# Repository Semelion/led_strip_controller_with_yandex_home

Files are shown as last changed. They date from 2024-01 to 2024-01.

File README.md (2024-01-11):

# led_strip_controller_with_yandex_home
Контролер с возможностью подключения к умному дому Яндекс

Идея проекта сделать основу для проектов умного дома с интеграцией в умный дом Яндекс. Изначально возникла потребность управлять светодиодной лентой с возможностью димирования, но представленные контроллеры не внушали доверия

### Компоненты
- esp8266 для управления
- оптопары для управления транзисторами и другой нагрузкой 5 вольт
- транзистор IRF44N для управления светодиодной ленты
- кнопка без фиксации с подсветкой
- блок питания 12 вольт (расчитанный по мощности под ленту)
- понижающий dc-dc преобразователь для питания платы и компонентов

## Печатная плата
Печатная плата спроектирована в KiCad, исходники можно посмотреть в `kitchen_light_pcb/`, а библиотеки компенонтов использованные лежат в `kicad_lib`

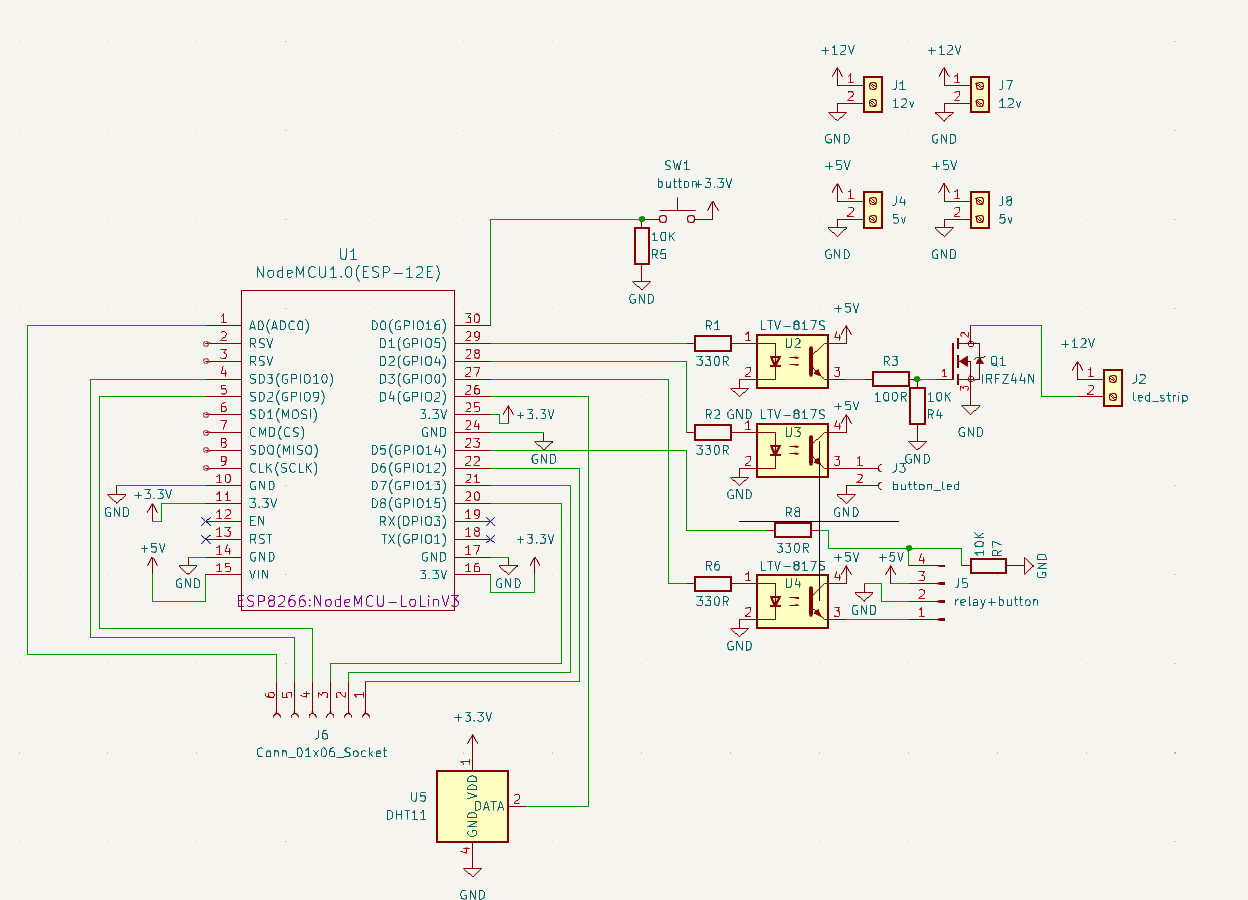
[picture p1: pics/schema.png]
Схема печатной платы

Схема печатной платы

- Разъем J2 для подключения светодиодной ленты
- J1, J7 разьемы 12 вольт на вход
- J4, J8 разьемы 5 вольт на вход
- J6 разьем подключенный к ESP, для подключения чего либо если понадобится
- есть датчик температуры и влажности DHT22
- J5 задумывается для использования реле и кнопки, чтобы встроить в выключатель без нуля
- SW1 контакты для кнопки, в моем случае это внешняя кнопка, крепится в низ шкафа над плитой
- J3 контакты для подсветки кнопки

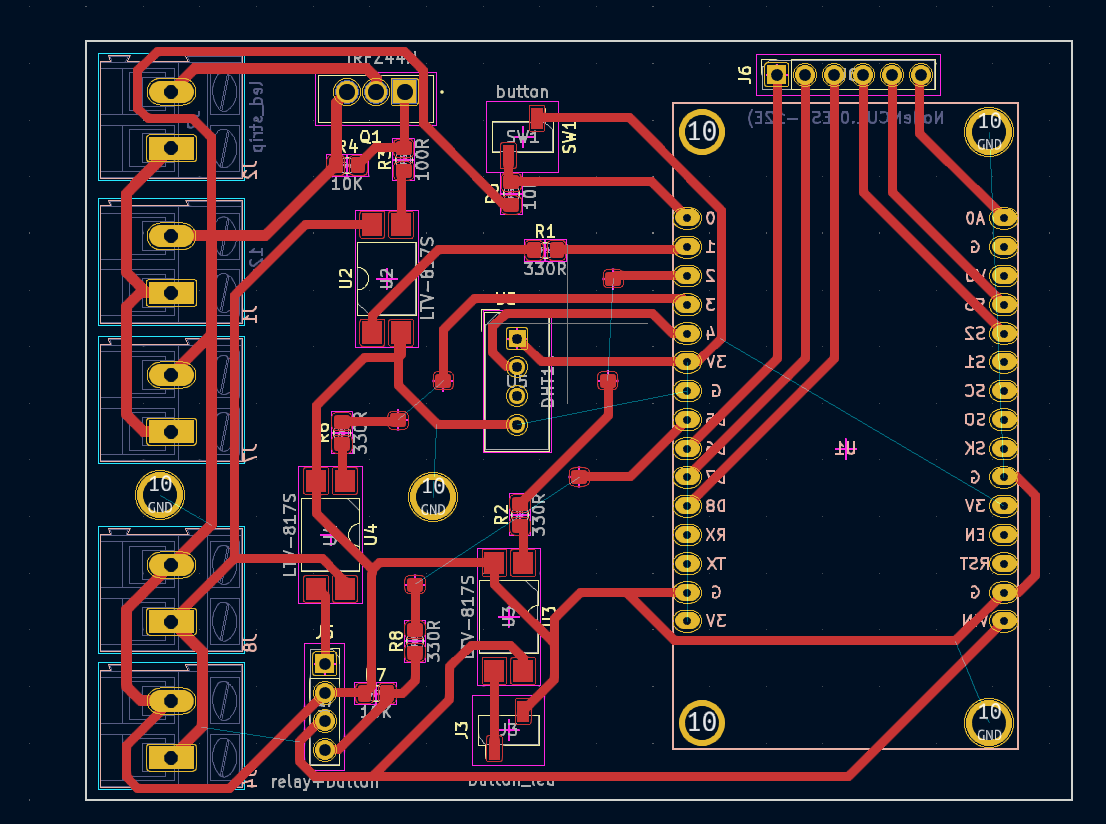
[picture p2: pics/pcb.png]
Разведение печатной платы

Разведение печатной платы

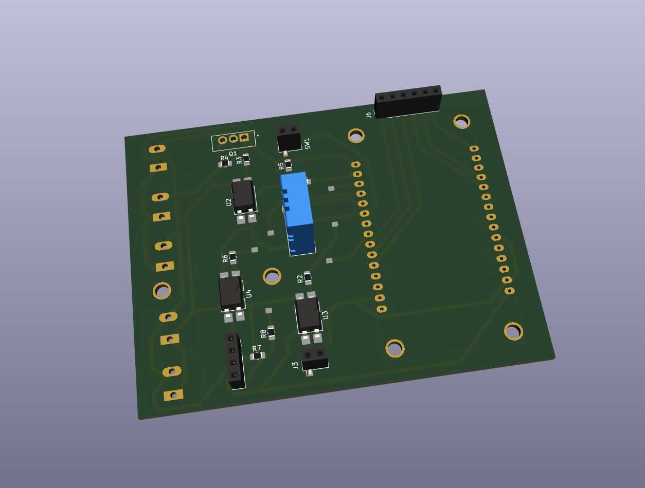
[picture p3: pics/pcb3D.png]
Печатная плата в 3D

Печатная плата в 3D

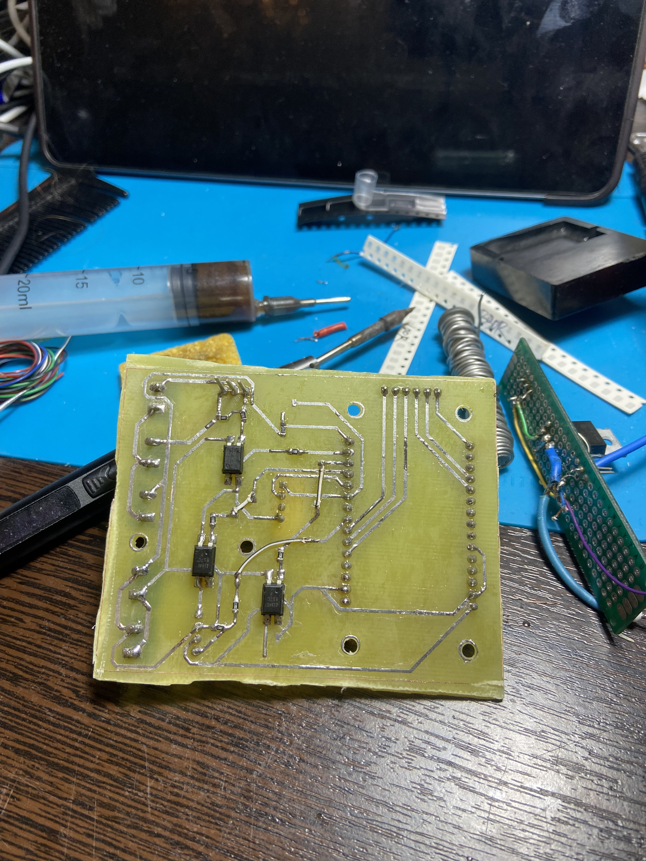
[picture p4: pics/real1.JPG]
Печатная плата в жизни


Печатная плата в жизни
Печатная плата в жизни, сделанная по методу ЛУТ

## Код
Файл с кодом: `controller_code/controller_code.ino`  
В коде необходимо прописать параметры под ваши условия:
``` cpp
#define ssid  "" //write your SSID
#define password  "" //write password
#define mqtt_server "" //url or ip mqtt server
#define mqtt_port 1883 //port for mqtt server
```
Тут необходимо указать данные вашего WIFI и MQTT сервера  
Как вариант найти MQTT сервер можно [тут.](https://mntolia.com/10-free-public-private-mqtt-brokers-for-testing-prototyping/)

Также надо прописать топики для управления лентой, они должны быть уникальными, особенно при использовании публичного сервера, так как кто нибудь может туда публиковать значения
```cpp
#define LAMP_STATE_TOPIC "kitchen/lamp/state" //поменять на свои
#define LAMP_POWER_TOPIC "kitchen/lamp/power"
```

Прошивать надо через Arduino IDE, гайд [тут.](https://wiki.iarduino.ru/page/wemos_start/)

### Подключение к Алисе
Интеграция в умный дом происходит через навык "Домовёнок Кузя", у автора есть подробные гайды на [сайте](https://alexstar.ru/smarthome) и на [Ютуб](https://www.youtube.com/watch?v=lm6nl2dc3VI&t=30s)

Необходимо будет зайти под своим аккаунтом Яндекс, настроить правила MQTT на включение, выключение и изменения яркости, а также создать виртуальное устройство к которому привязать правила MQTT

## Результат работы
<video controls>
  <source src="pics/video.mov" type="video/mp4">
</video>
video

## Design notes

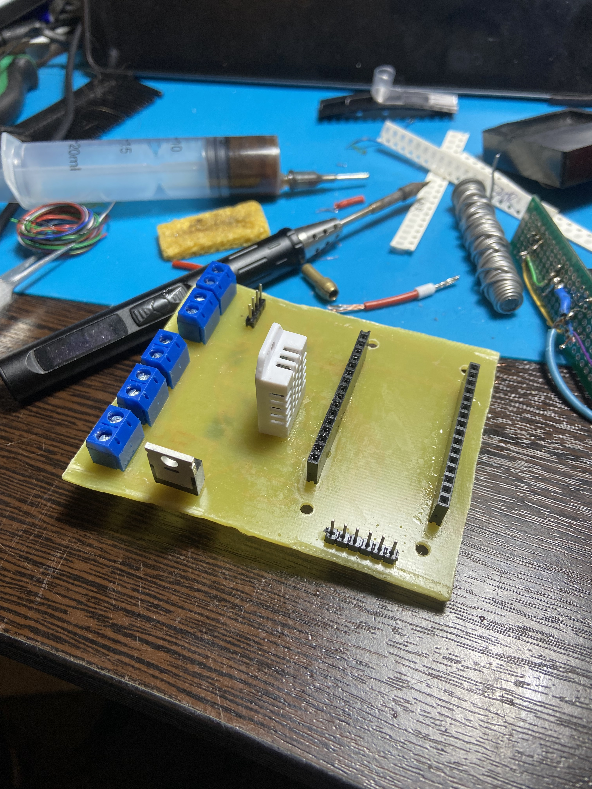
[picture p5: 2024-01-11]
pics/real2.JPG

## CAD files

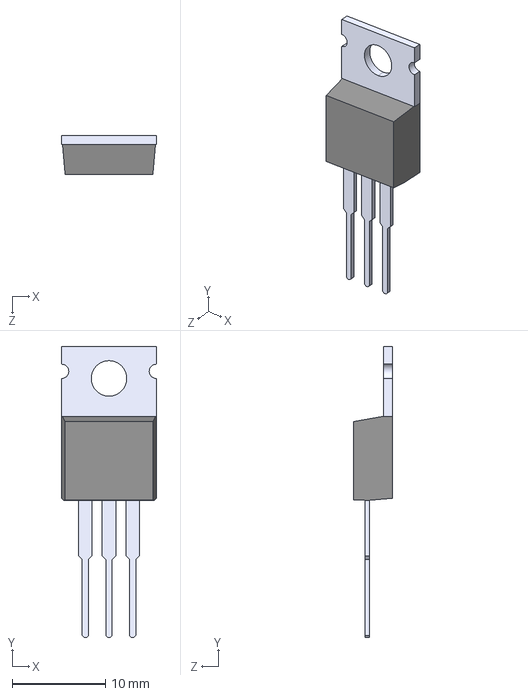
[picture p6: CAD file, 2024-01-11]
kicad_lib/IRFZ44N/IRFZ44N.step
10.2 x 31.2 x 4.19 mm

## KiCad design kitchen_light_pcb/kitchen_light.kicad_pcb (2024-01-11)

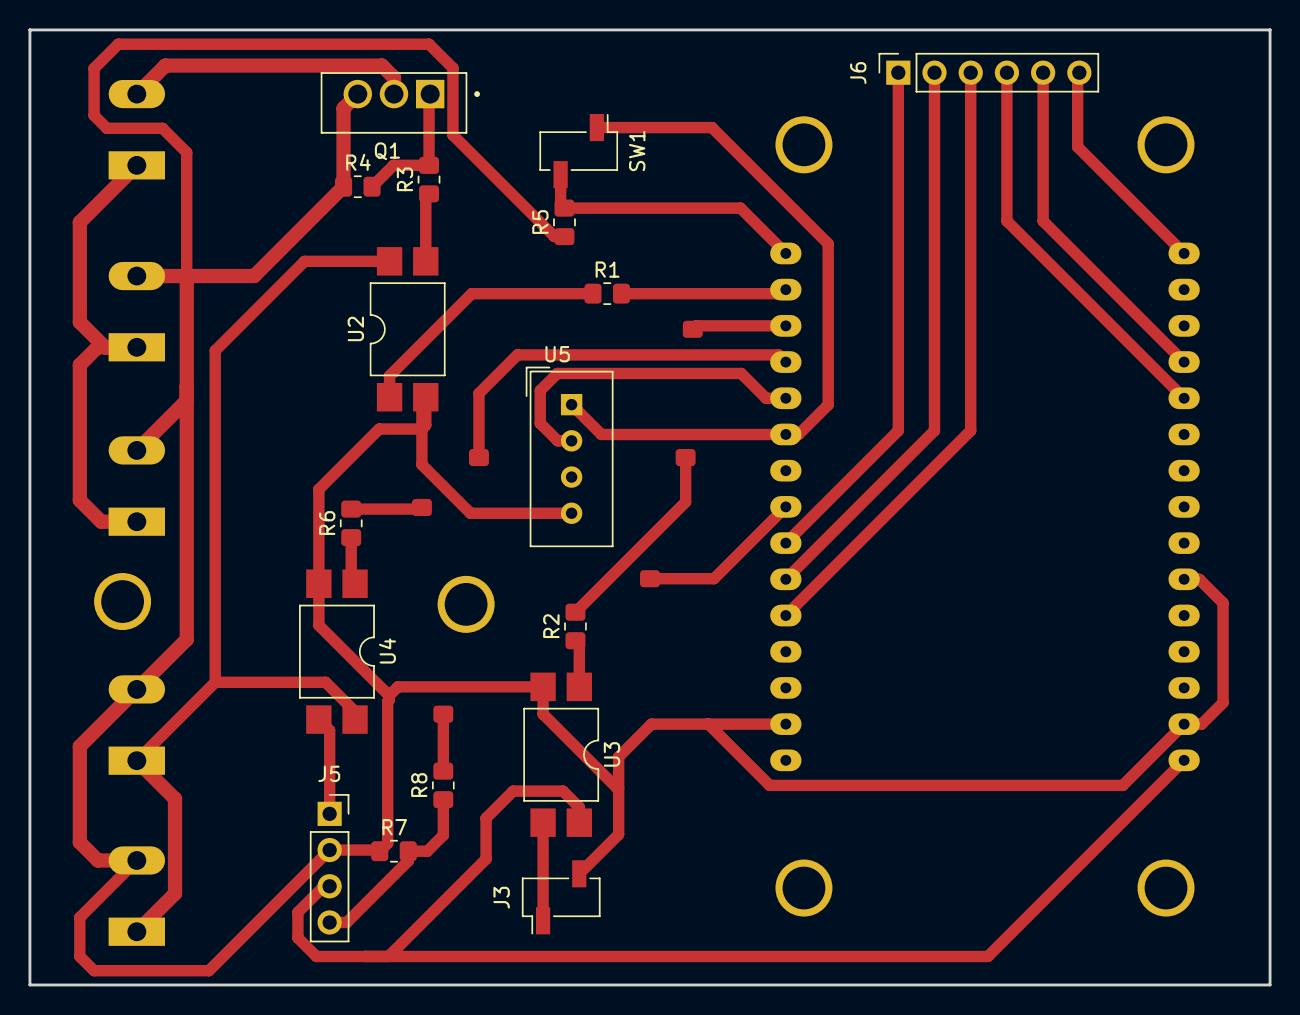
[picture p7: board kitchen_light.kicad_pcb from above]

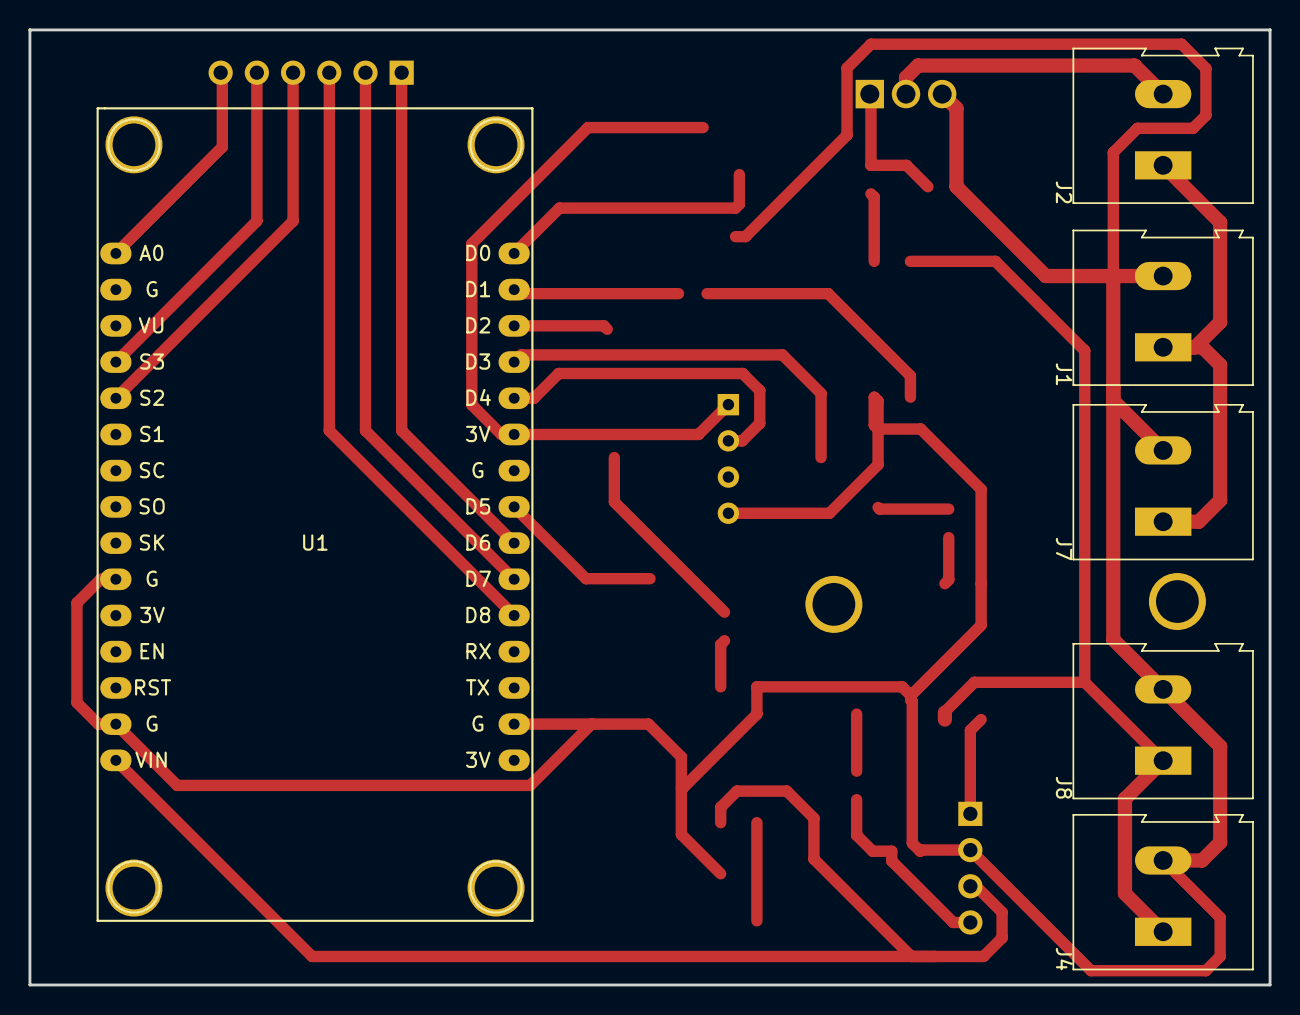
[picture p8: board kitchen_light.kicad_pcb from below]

Board: 2 copper layers, 87.0 x 67.0 mm, 23 parts (6 on the bottom side), 25 nets.

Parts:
J1, J7: 12v; TerminalBlock_Altech_AK300-2_P5.00mm
J2: led_strip; TerminalBlock_Altech_AK300-2_P5.00mm
J3: button_led; PinSocket_1x02_P2.54mm_Vertical_SMD_Pin1Left
J4, J8: 5v; TerminalBlock_Altech_AK300-2_P5.00mm
J5: relay+button; PinSocket_1x04_P2.54mm_Vertical
J6: Conn_01x06_Socket; PinSocket_1x06_P2.54mm_Vertical
Q1: IRFZ44N; TO254P1016X419X2286-3
R1, R2, R6, R8: 330R; R_0805_2012Metric_Pad1.20x1.40mm_HandSolder
R3: 100R; R_0805_2012Metric_Pad1.20x1.40mm_HandSolder
R4, R5, R7: 10K; R_0805_2012Metric_Pad1.20x1.40mm_HandSolder
SW1: button; PinSocket_1x02_P2.54mm_Vertical_SMD_Pin1Left
U1: NodeMCU1.0(ESP-12E); NodeMCU-LoLinV3
U2, U3, U4: LTV-817S; SMDIP-4_W9.53mm
U5: DHT11; Aosong_DHT11_5.5x12.0_P2.54mm

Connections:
+3.3V: SW1.1 (A), U1.11 (3.3V), U1.16 (3.3V), U1.25 (3.3V), U5.1 (VDD)
+5V: J4.1, J5.3, J8.1, U1.15 (VIN), U2.4, U3.4, U4.4
+12V: J1.1, J2.1, J7.1
GND: J1.2, J3.2, J4.2, J5.2, J7.2, J8.2, Q1.3, R4.1, R5.1, R7.1, U1.10 (GND), U1.14 (GND), U1.17 (GND), U1.24 (GND), U2.2, U3.2, U4.2, U5.4 (GND)
unnamed: J2.2, Q1.2
unnamed: J3.1, U3.3
unnamed: J5.1, U4.3
unnamed: J5.4, R7.2, R8.1
unnamed: J6.1, U1.22 (D6(GPIO12))
unnamed: J6.2, U1.21 (D7(GPIO13))
unnamed: J6.3, U1.20 (D8(GPIO15))
unnamed: J6.4, U1.5 (SD2(GPIO9))
unnamed: J6.5, U1.4 (SD3(GPIO10))
unnamed: J6.6, U1.1 (A0(ADC0))
unnamed: Q1.1, R3.2, R4.2
unnamed: R1.1, U2.1
unnamed: R2.1, U3.1
unnamed: R3.1, U2.3
unnamed: R6.1, U4.1
unnamed: R5.2, SW1.2 (A), U1.30 (D0(GPIO16))
unnamed: R1.2, U1.29 (D1(GPIO5))
unnamed: R2.2, U1.28 (D2(GPIO4))
unnamed: R6.2, U1.27 (D3(GPIO0))
unnamed: U1.26 (D4(GPIO2)), U5.2 (DATA)
unnamed: R8.2, U1.23 (D5(GPIO14))

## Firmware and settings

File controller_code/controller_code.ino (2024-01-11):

#include <ESP8266WiFi.h>
#include <PubSubClient.h>

#define ssid  "" //write your SSID
#define password  "" //write password
#define mqtt_server "" //url or ip mqtt server
#define mqtt_port 1883 //port for mqtt server

#define LAMP_STATE_TOPIC "kitchen/lamp/state"
#define LAMP_POWER_TOPIC "kitchen/lamp/power"

#define pinLed 5
#define buttonPin 16
#define button_LED_Pin 4

bool state = false;
int power = 0;

WiFiClient espClient;
PubSubClient client(espClient);

void setup_wifi() {
  delay(10);
  // We start by connecting to a WiFi network
  Serial.println();
  Serial.print("Connecting to ");
  Serial.println(ssid);
  WiFi.mode(WIFI_STA);
  WiFi.begin(ssid, password);
  while (WiFi.status() != WL_CONNECTED) {
    delay(500);
    Serial.print(".");
  }
  randomSeed(micros());
  Serial.println("");
  Serial.println("WiFi connected");
  Serial.println("IP address: ");
  Serial.println(WiFi.localIP());
}

void callback(char* topic, byte* payload, unsigned int length) {
  Serial.print("Message arrived [");
  Serial.print(topic);
  Serial.print("] ");

  String input = "";
  for (int i = 0; i < length; i++) {
    Serial.print((char)payload[i]);
    input += (char)payload[i];
  }
  Serial.println();
  if (String(topic) == LAMP_STATE_TOPIC) {
    state = input.toInt();
    analogWrite(pinLed, power*state);
    digitalWrite(button_LED_Pin, !state);
  }

  if (String(topic) == LAMP_STATE_TOPIC) {
    power = map(input.toInt(), 0, 100, 0, 255);
    analogWrite(pinLed, power * state);
    digitalWrite(button_LED_Pin, !state);
  }

}

void reconnect() {
  // Loop until we're reconnected
  if(WiFi.status() != WL_CONNECTED)
    setup_wifi();

  while (!client.connected()) {
    Serial.print("Attempting MQTT connection...");
    // Create a random client ID
    String clientId = "ESP8266Client-";
    clientId += String(random(0xffff), HEX);
    // Attempt to connect
    if (client.connect(clientId.c_str())) {
      Serial.println("connected");
      client.subscribe(LAMP_STATE_TOPIC);
      client.subscribe(LAMP_POWER_TOPIC);
    } else {
      Serial.print("failed, rc=");
      Serial.print(client.state());
      Serial.println(" try again in 5 seconds");
      // Wait 5 seconds before retrying
      delay(5000);
    }
  }
}


void setup() {
  pinMode(pinLed, OUTPUT);
  pinMode(buttonPin, INPUT);
  pinMode(button_LED_Pin, OUTPUT);

  Serial.begin(115200);

  setup_wifi();
  client.setServer(mqtt_server, mqtt_port);
  client.setCallback(callback);
}

void loop() {

  if (!client.connected()) {
    reconnect();
  }
  client.loop();
  if (digitalRead(buttonPin) == HIGH) {
    while (digitalRead(buttonPin) == HIGH);
    Serial.print("Rbutton:   ");
    Serial.println(state);
    if (state == true)
      client.publish("semelion/kitchen/lamp/state", "0");
    else
      client.publish("semelion/kitchen/lamp/state", "1");
    delay(300);
  }

}
